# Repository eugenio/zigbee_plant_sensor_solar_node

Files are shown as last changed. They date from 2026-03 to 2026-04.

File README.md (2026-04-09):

# Zigbee Plant Sensor Solar Node

Solar-powered environmental monitoring node for outdoor plant care. Measures temperature, humidity, light, soil moisture, and battery state via Zigbee 802.15.4 — integrates with Home Assistant, Zigbee2MQTT, and ZHA.

## Motivation

Commercial plant sensors are either battery-hungry, lack solar charging, or miss key measurements. This node combines an MPPT solar charger with deep-sleep Zigbee to achieve indefinite outdoor operation while reporting six sensor channels.

## Hardware Overview

| Block | Component | Function |
| --- | --- | --- |
| MCU | ESP32-C6-MINI-1-N4 | Zigbee 802.15.4 / WiFi / BLE, 4MB flash |
| MPPT Charger | SPV1040T | Autonomous solar boost charger, 5W max  |
| LDO | HT7833 | 3.3V 500mA, 4uA quiescent |
| Battery Protection | XB3306D | Overcharge / overdischarge / overcurrent |
| Temp/Humidity | SHT40 | +/-0.2 degC, +/-1.8% RH (onboard) |
| Ambient Light | VEML7700 | 0.0036 - 120k lux |
| Fuel Gauge | MAX17048 | Li-Po SOC estimation, low-battery alert |
| External Temp | ADS1115 + NTC 10k  | 0.1 degC resolution, metal-tip probe |
| Expansion | 2x Qwiic I2C | Soil moisture, EC sensor |

**Board**: 60 x 48 mm, 4-layer, 1.6mm FR4

## Quick Start

```bash
# 1. Install atopile
pip install atopile

# 2. Clone and build
git clone <repo-url> && cd zigbee_plant_sensor_solar_node
ato build

# 3. Open PCB in KiCad
kicad layouts/default/default.kicad_pcb
```

## Project Structure

```text
.
├── main.ato                    # Top-level schematic (App module)
├── micromppt.ato               # MPPT solar charger (SPV1040T)
├── ldo.ato                     # 3.3V LDO (HT7833)
├── loadswitch.ato              # P-FET high-side load switch (SI2301CDS)
├── ntc_adc.ato                 # External NTC thermistor (ADS1115)
├── xiao_esp32c6.ato            # ESP32-C6 MCU driver
├── ato.yaml                    # Atopile project config + dependencies
├── pixi.toml                   # Pixi environment config
├── parts/                      # Component packages (32 parts, 4 files each)
│   ├── Texas_Instruments_ADS1115IRUGR/   # .ato + .kicad_mod + .kicad_sym + .step
│   ├── STMicroelectronics_SPV1040T/
│   ├── Espressif_Systems_ESP32_C6_MINI_1_N4/
│   └── ...                     # Resistors, caps, connectors, ICs
├── layouts/default/            # KiCad PCB layout (60x48mm, 4-layer)
│   ├── default.kicad_pcb
│   ├── default.kicad_sch
│   └── default.kicad_pro
├── docs/
│   ├── pcb_placement_strategy.md
│   ├── power_budget.md
│   ├── uml/architecture.puml  # System block diagram
│   └── adr/ADR-001-external-ntc-thermistor.md
└── scripts/
    └── place_components.py     # Automated PCB placement

176 tracked files. Atopile dependencies (sensirion-sht40, vishay-veml7700,
maxim-max17048, sparkfun-qwiic) are gitignored and reinstalled by `ato build`.
```

## Power Budget

| Mode | Current | Duration | Notes |
| --- | --- | --- | --- |
| Deep Sleep | ~82 uA | 99% of time | Fuel gauge + LDO quiescent |
| Active (sense + TX)| ~120 mA | ~500 ms | Zigbee transmit burst |
| Solar input | 200-400 mA | Daylight hours | 5V / 1W panel via MPPT |

See [docs/power_budget.md](docs/power_budget.md) for detailed analysis.

## Architecture

See [docs/uml/architecture.puml](docs/uml/architecture.puml) for the system block diagram.

## License

MIT

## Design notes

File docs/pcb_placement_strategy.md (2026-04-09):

# PCB Placement Strategy — Zigbee Plant Sensor Solar Node

## Board Parameters
- **PCB file**: `layouts/default/default.kicad_pcb`
- **Current size**: 245.5 x 137.5 mm (oversized — target ~60x48mm per enclosure)
- **Layers**: 4 (2-signal + 2-ground/power recommended)
- **Footprints**: 60 total, 235 pads, 0 tracks (unrouted)
- **Stack**: 1.6mm FR4

## Functional Blocks (placement groups)

### Block A — Solar MPPT Charger (SPV1040T)
**Components**: SPV1040T IC, L1 (XAL6060 inductor), Cin (10µF), Cout1 (4.7µF), Cout2 (10µF), R1/R2 (voltage divider 1%), R3, Rf1, Rf2, Rs (10mΩ sense), Cinsns, Coutsns, Cf, SRV05-4 (ESD), D_rpv (reverse polarity Schottky)
**Connectors**: J_solar (JST PH 2-pin), J_battery (JST PH 2-pin)
**Placement rules**:
- Keep inductor L1 within 3mm of SPV1040T LX pin
- Cin close to VIN, Cout1/Cout2 close to VOUT
- Rs (current sense) between IC VOUT and battery output — short, wide traces
- Voltage divider R1/R2 near VCTRL pin — keep traces short (high impedance)
- Solar connector at board edge
- Battery connector at board edge (same side or adjacent)
- Group entire MPPT section in one corner

### Block B — Battery Protection (XB3306D)
**Components**: XB3306D IC, C_bpc (100nF), R_bpc (100Ω)
**Placement**: Adjacent to battery connector, between MPPT output and battery JST

### Block C — LDO Power (HT7833)
**Components**: HT7833 IC, c_in (1µF), c_out (1µF), c_bulk (100µF 0805)
**Placement rules**:
- Between battery rail (Block A output) and 3.3V rail (Block D input)
- c_bulk (100µF) as close to VOUT as possible — critical for TX transient
- c_in close to VIN pin
- Keep short, wide power traces from battery to LDO to MCU

### Block D — ESP32-C6 MCU
**Components**: ESP32-C6-MINI-1-N4 module, c_dec_1 (10µF), c_dec_2 (100nF), r_en (10k), c_en (1µF), r_boot (10k), btn_boot, btn_reset, USB-C connector, r_cc1/r_cc2 (5.1k), USB ESD (SRV05-4)
**Placement rules**:
- **CRITICAL: Antenna keepout** — 3.5mm clearance from module edge (antenna end) on ALL copper layers. No traces, pours, or vias in this zone.
- Antenna must point toward board edge or overhang — never toward ground plane
- Place module so antenna faces AWAY from MPPT switching noise
- Decoupling caps c_dec_1 and c_dec_2 within 2mm of P3V3 pin
- USB-C connector at board edge, close to IO12/IO13 pads
- Boot/reset buttons accessible from board edge
- Keep I2C lines (IO6/IO7) routed toward sensor area

### Block E — Sensors (on switched power rail)
**Components**: SHT40 (DFN-4), VEML7700 (LED-SMD-4P), decoupling caps (2x 100nF)
**Placement rules**:
- SHT40: Away from heat sources (LDO, MPPT, MCU). Ideally near board edge with thermal isolation slot
- VEML7700: Near board edge with unobstructed view (light sensor — no tall components nearby)
- Both on same I2C bus — minimize trace length to MCU IO6/IO7

### Block F — Fuel Gauge (always on, main 3.3V)
**Components**: MAX17048 (TDFN-8), bypass_cap (1µF), battery_cap (1µF), q_pulldown (10k), alert_pullup (10k)
**Placement**: Near battery connection (senses CELL voltage) and close to MCU (I2C + ALERT to GPIO2)

### Block G — Qwiic Connectors
**Components**: 2x BM04B-SRSS-TB (4-pin SMD)
**Placement**: Board edge, accessible for cable connection. Same side preferred.

### Block H — Load Switches (2x SI2301CDS P-FET)
**Components per switch**: SI2301CDS (SOT-23), r_gate_pu (100k), r_gate (10k)
- **MPPT gate**: Between battery rail and MPPT power input. Near Block A.
- **Sensor gate**: Between 3.3V rail and sensor power rail. Near Block E.

### Block I — I2C Pull-ups
**Components**: r_sda_pu (2.2k), r_scl_pu (2.2k)
**Placement**: Central location near MCU, on the I2C bus trunk before it fans out to sensors/Qwiic

### Block J — External NTC Thermistor (ADS1115)
**Components**: ADS1115IRUGR (X2QFN-10), R_ref (10k 0.1% 0402), C_dec (100nF 0402), CN_ntc (JST PH 2-pin)
**Placement rules**:
- ADS1115 near fuel gauge (Block F) — both on I2C bus, both always-on
- R_ref within 3mm of ADS1115 AIN0 pin (short high-impedance trace)
- C_dec within 2mm of ADS1115 VDD pin
- CN_ntc at board edge — NTC probe cable exits enclosure, only metal tip protrudes
- Keep analog input traces away from MPPT switching noise and I2C clock lines
- Guard AIN0 trace with GND on adjacent layers

### Block K — Mounting Holes
**Components**: 4x MountingHole_3.2_M3
**Placement**: 4 corners of the board, inset ~3mm from edges

## Recommended Floor Plan (60x48mm target)

```
┌─────────────────────────────────────────────────────────┐
│ [MH]                                             [MH]  │
│                                                         │
│  ┌─────────┐  ┌──────────┐  ┌───────────────────────┐  │
│  │ MPPT    │  │ LDO      │  │ ESP32-C6-MINI-1       │  │
│  │ Block A │  │ Block C  │  │ Block D               │  │
│  │         │  │ +100µF   │  │                       │  │
│  │ L1  IC  │  │          │  │         ┌─────────┐   │  │
│  │         │  │          │  │         │ ANTENNA │   │  │
│  └─────────┘  └──────────┘  │         │ KEEPOUT │   │  │
│  [J_solar]                   │         └─────────┘   │  │
│  [J_batt] [BPC]             └───────────────────────┘  │
│                                                         │
│  ┌───────┐ ┌───────┐  [I2C PU]  ┌────┐ ┌────┐         │
│  │SHT40  │ │VEML   │            │Qwc1│ │Qwc2│  [USB-C]│
│  │Block E│ │7700   │  [Fuel     └────┘ └────┘         │
│  └───────┘ └───────┘   Gauge]    Block G               │
│  [CN_ntc]   [ADS1115]  Block F                         │
│              Block J                                    │
│ [MH]                                             [MH]  │
└─────────────────────────────────────────────────────────┘

Power flow: Solar → MPPT → Battery → LDO → 3.3V → MCU/Sensors
Signal flow: Sensors → I2C bus → MCU → Zigbee antenna (RF out)
```

## Placement Priority Order

1. **ESP32-C6 module** — largest component, antenna determines board edge orientation
2. **MPPT IC + inductor** — high-current switching, needs tight layout
3. **LDO + bulk cap** — power path between MPPT and MCU
4. **Connectors** (solar, battery, USB-C, Qwiic) — board edges
5. **Sensors** (SHT40, VEML7700) — thermal/optical considerations
6. **Fuel gauge** (MAX17048) — near battery + MCU
7. **Load switches** — in power path, near their respective blocks
8. **NTC ADC** (ADS1115) — near fuel gauge, NTC connector at board edge
9. **Passives** — close to their parent ICs
10. **Mounting holes** — 4 corners

## Critical Layout Rules

1. **Antenna keepout**: 3.5mm clearance, no copper on any layer
2. **MPPT switching loop**: Minimize area of L1→LX→VOUT→Cout→GND loop
3. **Current sense**: Rs (10mΩ) Kelvin connection — separate sense and power traces
4. **Ground plane**: Continuous on layer 2, split only if necessary between analog/digital
5. **Thermal relief**: SHT40 needs thermal isolation from hot components
6. **High-impedance traces**: R1/R2 voltage divider, MPPT sense lines — guard with ground
7. **Power traces**: Battery and 3.3V rails minimum 0.5mm width, 1mm preferred
8. **NTC analog trace**: AIN0 from R_ref/NTC junction to ADS1115 — short, guarded with GND, away from MPPT/I2C clock

## GPIO Quick Reference

| GPIO | Function | Direction | Connected To |
|---|---|---|---|
| IO0  | MPPT gate | Output (active low) | SI2301CDS gate → MPPT power |
| IO1  | Sensor gate | Output (active low) | SI2301CDS gate → sensor rail |
| IO2  | Battery alert | Input (active low) | MAX17048 nALRT |
| IO6  | I2C SDA | Bidirectional | All sensors + Qwiic |
| IO7  | I2C SCL | Output | All sensors + Qwiic |
| IO9  | Boot select | Input (pulled high) | Boot button to GND |
| IO12 | USB D- | Bidirectional | USB-C connector |
| IO13 | USB D+ | Bidirectional | USB-C connector |
| IO16 | UART TX | Output | Debug header (optional) |
| IO17 | UART RX | Input | Debug header (optional) |

## How to Execute

After restarting Claude Code (to load the kicad-pcb MCP server):

```
Use the pcb-placement-specialist agent to place components according to
this strategy document. The KiCad MCP tools are configured as "kicad-pcb"
and expose: list_pcb_footprints, get_pcb_statistics, setup_pcb_layout,
analyze_pcb_nets, run_drc, export_gerber.

PCB file: layouts/default/default.kicad_pcb
Strategy: docs/pcb_placement_strategy.md
```

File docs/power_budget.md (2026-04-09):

# Power Budget — Zigbee Plant Sensor Solar Node

## Component Power Consumption

| Component | Function | V_supply | Active Current | Sleep Current |
|---|---|---|---|---|
| ESP32-C6-MINI-1-N4 | MCU + Zigbee | 3.3V | 120 mA (TX @ 0 dBm), 73 mA (RX), 19 mA (CPU only) | 7 uA (deep sleep) |
| SHT40 | Temp/Humidity | 1.08-3.6V | 150 uA | 0.08 uA |
| VEML7700 | Light Sensor | 2.5-3.6V | 45 uA | 0.5 uA |
| MAX17048 | Fuel Gauge | 2.5-4.5V | 23 uA | 4 uA |
| SPV1040T | MPPT Charger | 0.3-5.5V | N/A | 60 uA (quiescent) |
| HT7833 | 3.3V LDO | 3.6-8V in | pass-through | 7 uA |
| XB3306D | Battery Protection | 2.5-6.0V | pass-through | 3 uA |

## Operating Parameters

- Readings every 5 minutes (288/day)
- Active duration per reading: ~500 ms (200 ms sensor read + 300 ms Zigbee TX/ACK)
- Battery: 3.7V nominal LiPo

## Active Current Budget (per 500 ms reading)

| Phase | Duration | ESP32-C6 | Sensors | Other | Subtotal |
|---|---|---|---|---|---|
| Sensor read (CPU, no RF) | 200 ms | 19 mA | ~0.2 mA | ~0.03 mA | ~19.2 mA |
| Zigbee TX + RX ACK | 300 ms | 120 mA | — | ~0.03 mA | ~120 mA |
| **Weighted average** | **500 ms** | | | | **~80 mA** |

With 1.2x safety margin: **~96 mA average per active period**

## Sleep Current Budget

| Component | Current |
|---|---|
| ESP32-C6 (deep sleep) | 7.0 uA |
| SHT40 (idle) | 0.08 uA |
| VEML7700 (shutdown) | 0.5 uA |
| MAX17048 (hibernate) | 4.0 uA |
| SPV1040T (quiescent) | 60.0 uA |
| HT7833 (quiescent) | 7.0 uA |
| XB3306D (standby) | 3.0 uA |
| **Total** | **81.6 uA** |

Note: SPV1040T dominates sleep budget at 73% of total.

## Daily Energy Budget

### At 3.3V rail

| Mode | Current | Time/day | Energy |
|---|---|---|---|
| Active | 96 mA | 144 s (0.04 h) | 3.84 mAh / 12.67 mWh |
| Sleep | 81.6 uA | 23.96 h | 1.96 mAh / 6.45 mWh |
| **Subtotal** | | | **5.80 mAh / 19.12 mWh** |

### At battery level

- HT7833 LDO efficiency: Vout/Vin = 3.3V/3.7V = 89.2%
- SPV1040T quiescent (direct from battery): 60 uA x 24h x 3.7V = 5.33 mWh/day
- XB3306D (direct from battery): 3 uA x 24h x 3.7V = 0.27 mWh/day

| Item | Energy/day |
|---|---|
| 3.3V rail (through LDO) | 21.43 mWh |
| SPV1040T quiescent | 5.33 mWh |
| XB3306D standby | 0.27 mWh |
| **Total from battery** | **~27 mWh/day** |

**With safety margin: ~30 mWh/day**

## Battery Autonomy (no solar)

| Battery | Capacity | Realistic Days (x0.7 derating) |
|---|---|---|
| 500 mAh | 1.85 Wh | ~43 days |
| 1000 mAh | 3.7 Wh | ~86 days |
| 2000 mAh | 7.4 Wh | ~173 days |

## Solar Panel Sizing

Efficiency chain:
- SPV1040 charger: ~90%
- Battery charge/discharge: ~90%
- Panel derating (angle, clouds, aging): ~70%
- **Combined: 56.7%**

Required solar input: 30 mWh / 0.567 = **52.9 mWh/day**

| Panel | Rated Power | Peak Sun Hours Needed |
|---|---|---|
| 0.5W (60x60mm) | 500 mW | 6.3 min |
| 1W (110x70mm) | 1000 mW | 3.2 min |
| 2W (110x136mm) | 2000 mW | 1.6 min |

## Selected Configuration

- **Solar panel**: ~2W, **4-cell** (Vmpp ~2.0-2.2V, Impp ~0.9-1.0A)
  - CRITICAL: SPV1040T is a boost-only converter (Vin < Vout required).
    A 5V panel (Voc ~6.5V) exceeds Vin_max=5.5V and prevents MPPT tracking.
    Must use a low-voltage panel where Vmpp < Vbat (4.2V).
  - Alternative: replace SPV1040T with buck-boost MPPT (e.g., SPV1050, CN3791)
    if a 5V+ panel is preferred.
- **Battery**: 1000 mAh LiPo (3.7V nominal)
- **Battery autonomy**: ~86 days without sun (with MPPT gate: ~120+ days)
- **Solar sufficiency**: needs <2 minutes of direct sun per day

## Design Improvements (rev 2)

- **R1/R2 tolerance**: Changed from 10% to 1% — prevents overcharge (4.53V risk)
- **LDO bulk cap**: Added 100µF output cap — absorbs 120mA Zigbee TX transient
- **I2C pull-ups**: Centralized single 2.2k pair — was 6x10k stacked (3.3k effective)
- **Solar reverse protection**: Added Schottky diode on Vpv input
- **USB ESD**: Added SRV05-4 TVS on USB D+/D-
- **MPPT power gate**: P-FET load switch (SI2301CDS) on GPIO0 — saves 60µA at night
- **Sensor power gate**: P-FET load switch on GPIO1 — cuts external sensor power during sleep
- **Battery UVLO**: MAX17048 ALERT wired to GPIO2 — wakes MCU for low-battery shutdown
- **RF keepout**: Documented 3.5mm antenna clearance zone requirement

## ESP32-C6 802.15.4 TX Power Levels

| TX Power | Current |
|---|---|
| +19 dBm | 305 mA |
| +12 dBm | 190 mA |
| 0 dBm | 120 mA |
| -16 dBm | 86 mA |

Default assumption: 0 dBm (good indoor/outdoor range, reasonable power).

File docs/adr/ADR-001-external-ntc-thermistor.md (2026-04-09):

# ADR-001: External NTC Thermistor with ADS1115 ADC

## Status

Accepted

## Context

The onboard SHT40 temperature sensor is mounted on the PCB inside a solar-exposed enclosure. During sunny conditions, the PCB heats up significantly (measured 15-20 degC above ambient), making the onboard reading unreliable for true ambient temperature. The node needs accurate outdoor temperature for plant care decisions.

Requirements:
- Range: -30 to +100 degC
- Resolution: 0.1 degC
- Only the metal sensing tip protrudes from the enclosure
- Short cable (10-30 cm)
- Low cost, simple integration

## Decision

Use an external 10k NTC thermistor probe with a dedicated ADS1115 16-bit delta-sigma ADC for readout. The NTC connects via a JST PH 2-pin connector. A precision 10k 0.1% reference resistor (YAGEO RT0402BRD0710KL, 25ppm/degC) forms a voltage divider read by the ADS1115.

The ADS1115 is on the always-on 3.3V rail (not the switched sensor rail) with I2C address 0x48.

Firmware will use Steinhart-Hart 3-point calibration to achieve +/-0.1 degC absolute accuracy from a standard +/-1% NTC probe.

## Consequences

### Positive
- True ambient temperature independent of enclosure heating
- 0.02 degC ADC resolution (16-bit) far exceeds the 0.1 degC target
- ADS1115 shares existing I2C bus — no additional GPIOs needed
- NTC probe is cheap (~1-3 EUR) and mechanically simple

### Negative
- Adds 4 components to BOM: ADS1115 (1.92 EUR), precision resistor, decoupling cap, JST connector
- Requires firmware Steinhart-Hart calibration per probe
- NTC nonlinearity requires lookup table or polynomial for accuracy across full range

### Neutral
- ADS1115 has 4 analog inputs — 3 are unused and available for future sensors
- I2C bus now has 5 devices (SHT40, VEML7700, MAX17048, ADS1115, + Qwiic) — well within bus capacity

## Alternatives Considered

| Alternative | Why Rejected |
|---|---|
| ESP32-C6 internal ADC (12-bit) | INL +/-5 LSB gives +/-0.6 degC — insufficient for 0.1 degC target |
| External digital probe (DS18B20, 1-Wire) | Requires additional GPIO + 1-Wire protocol; 0.5 degC accuracy without calibration |
| External SHT40 on cable (I2C) | I2C not reliable over cables >10cm without bus extender; address conflict with onboard SHT40 |
| Pt1000 RTD | More linear and accurate but requires excitation current source or Wheatstone bridge — more complex circuit for marginal benefit over calibrated NTC |

## References

- ADS1115 datasheet: Texas Instruments SBAS444
- NTC Steinhart-Hart calibration: Steinhart & Hart, 1968, "Calibration curves for thermistors"
- YAGEO RT0402BRD0710KL: 10k 0.1% thin film, 25ppm/degC

---
*ADRs are immutable once Accepted. To revise, create a new ADR with status "Supersedes ADR-001".*

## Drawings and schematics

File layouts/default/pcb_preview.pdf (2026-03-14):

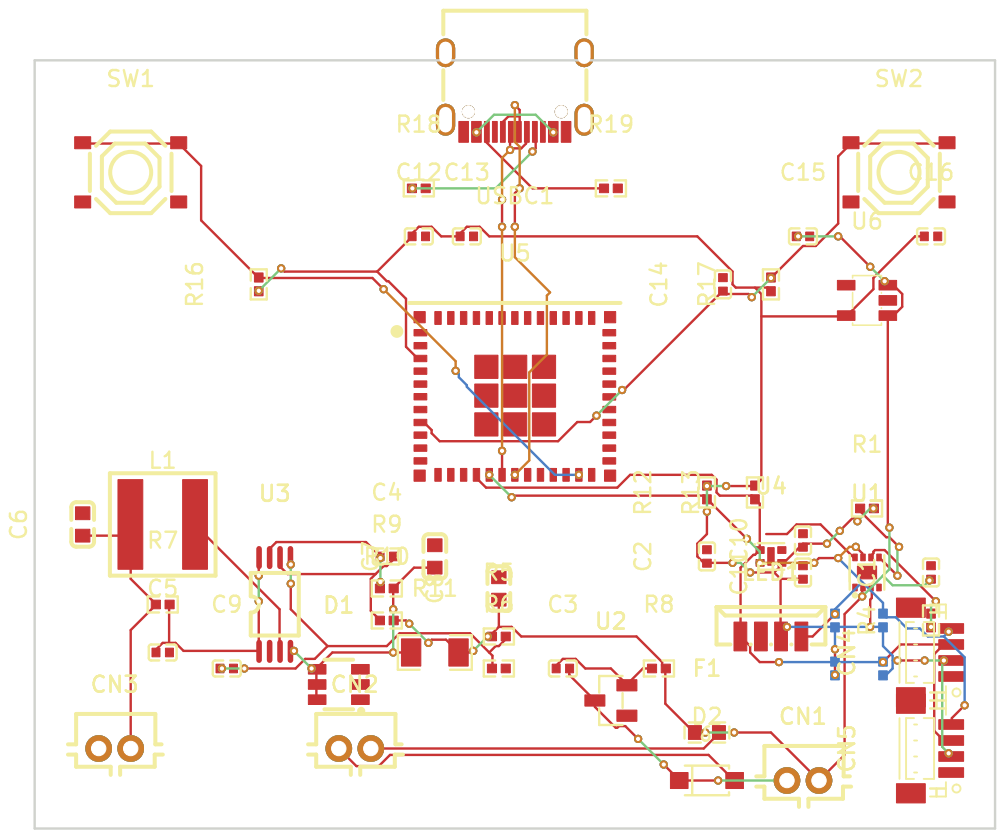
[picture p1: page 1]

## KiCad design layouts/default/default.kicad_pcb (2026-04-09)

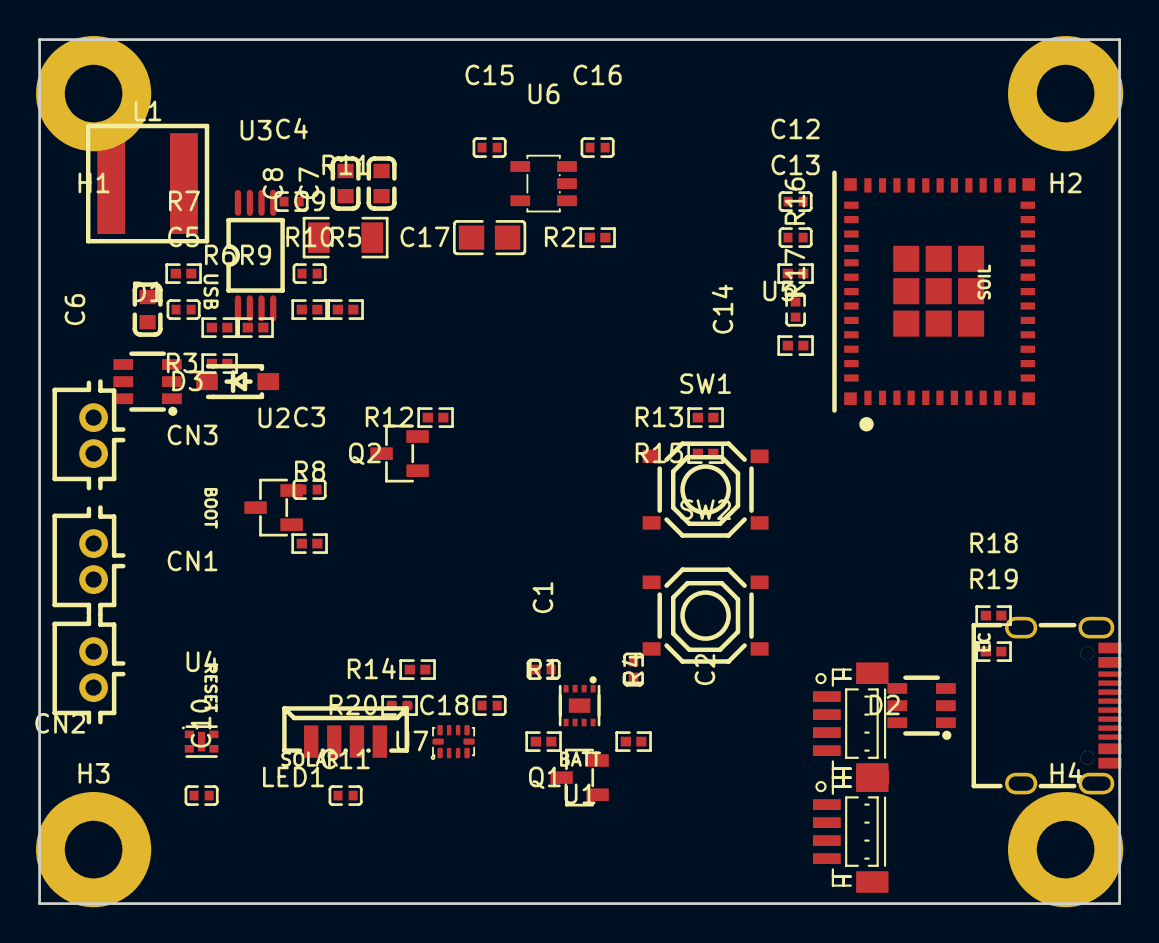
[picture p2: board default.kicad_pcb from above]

Board: 4 copper layers, 60.0 x 48.0 mm, 64 parts (0 on the bottom side), 28 nets, no tracks yet.

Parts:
C1, C2, C4, C14, C15, C16: 1µF ±10%; C0402
C3, C5, C10, C11, C13, C18: 100nF ±10%; C0402
C6, C8: 10µF ±10%; C0603
C7: 4.7µF ±10%; C0603
C9: 1nF ±10%; C0402
C12: 10µF ±20%; C0402
C17: 100µF ±20%; C0805
CN1, CN2, CN3: CONN-TH_B2B-PH-K-S
CN4, CN5: CONN-SMD_BM04B-SRSS-TB
D1, D2: SOT-23-6_L2.9-W1.6-P0.95-LS2.8-BR
D3: Vf {ℝ+}V; SOD-123_L2.7-W1.6-LS3.7-RD-1
H1, H2, H3, H4: MountingHole_3.2_M3
L1: L {ℝ+}H; IND-SMD_L6.6-W6.4
LED1: LED-SMD_4P-L6.8-W2.4_VEML7700-TR
Q1, Q2: SOT-23-3_L2.9-W1.3-P1.90-LS2.4-BR
R1, R4, R13, R15, R16, R17: 10kΩ ±1%; R0402
R2, R3: 2.2kΩ ±1%; R0402
R5: 1MΩ ±1%; R0402
R6: 422kΩ ±1%; R0402
R7, R9, R10: 1kΩ ±1%; R0402
R8: 100Ω ±1%; R0402
R11: 10mΩ ±1%; R1206
R12, R14: 100kΩ ±1%; R0402
R18, R19: 5.1kΩ ±1%; R0402
R20: R0402
SW1, SW2: SW-SMD_4P-L5.1-W5.1-P3.70-LS6.5-TL_H1.5
U1: TDFN-8_L2.0-W2.0-P0.50-BL-EP1.2
U2: SOT-23-3_L2.9-W1.3-P1.90-LS2.4-BR
U3: TSSOP-8_L4.4-W3.0-P0.65-LS6.4-BL
U4: DFN-4_L1.5-W1.5-P0.8-TL-EP
U5: WIFIM-SMD_61P-L16.6-W13.2-P0.80-ESP32-C6-MINI-1-N4
U6: SOT-23-5_L3.0-W1.7-P0.95-LS2.8-BR
U7: X2QFN-10_L2.0-W1.5-P0.50-BL
USBC1: USB-C_SMD-TYPE-C-31-M-12_1

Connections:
1: CN2.1, R20.2, U7.4
5: R1.1, U1.5, U5.5
17: D2.6, U5.17, USBC1.A7, USBC1.B7
18: D2.4, U5.18, USBC1.A6, USBC1.B6
A: R16.2, SW1.1, SW1.2, U5.23
A5: R18.1, USBC1.A5
B5: R19.1, USBC1.B5
C_bpc-power-hv: C3.1, R8.1, U2.2
Cf-power-hv: C4.1, R9.1, U3.7
Cf-power-lv: C4.2, R10.1, U3.6
Cinsns-power-hv: C5.1, R7.2, U3.1, U3.8
Cout1-power-hv: C7.1, D1.4, D1.5, D1.6, R9.2, R11.1, U3.4
Coutsns-power-hv: C9.1, R5.2, R6.1, U3.5
G: Q1.1, R12.2, R13.2
LX: L1.2, U3.3
QSTRT: R4.1, U1.6
SCL: CN4.4, CN5.4, LED1.1, R2.2, U1.7, U4.2, U5.16, U7.10
SDA: CN4.3, CN5.3, LED1.4, R3.2, U1.8, U4.1, U5.15, U7.9
Vbatr-lv: C3.2, CN1.2, U2.3
anode: CN3.1, D3.2
c_en-power-hv: C14.1, R17.2, SW2.1, SW2.2, U5.8
cathode: C6.1, D3.1, L1.1, R7.1
hv: C1.1, C2.1, C8.1, C10.1, C11.1, C12.1, C13.1, C15.1, C16.1, C17.1, C18.1, CN1.1, CN4.2, CN5.2, D2.5, LED1.2, Q1.2, Q2.2, Q2.3, R1.2, R2.1, R3.1, R5.1, R8.2, R10.2, R11.2, R12.1, R14.1, R16.1, R17.1, R20.1, U1.2, U1.3, U4.3, U5.3, U6.1, U6.3, U6.5, U7.8
line: R13.1, U5.12
lv: C1.2, C2.2, C5.2, C6.2, C7.2, C8.2, C9.2, C10.2, C11.2, C12.2, C13.2, C14.2, C15.2, C16.2, C17.2, C18.2, CN2.2, CN3.2, CN4.0, CN4.1, CN5.0, CN5.1, D1.1, D1.2, D1.3, D2.1, D2.2, D2.3, LED1.3, R4.2, R6.2, R18.2, R19.2, SW1.3, SW1.4, SW2.3, SW2.4, U1.1, U1.4, U1.9, U2.1, U3.2, U4.4, U4.5, U5.1, U5.2, U5.11, U5.14, U5.36, U5.37, U5.38, U5.39, U5.40, U5.41, U5.42, U5.43, U5.44, U5.45, U5.46, U5.47, U5.48, U5.49, U5.50, U5.51, U5.52, U5.53, U6.2, U7.1, U7.3, U7.5, U7.6, U7.7, USBC1.1, USBC1.2, USBC1.3, USBC1.4, USBC1.A1B12, USBC1.B1A12
power_usb-hv: USBC1.A4B9, USBC1.B4A9
sensor_gate-G: Q2.1, R14.2, R15.2
sensor_gate-enable-line: R15.1, U5.13

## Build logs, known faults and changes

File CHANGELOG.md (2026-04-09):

# Changelog

All notable changes to this project are documented here.
Format: [Keep a Changelog](https://keepachangelog.com/en/1.0.0/)

## [Unreleased]

### Added
- External NTC thermistor circuit: ADS1115 16-bit ADC + 10k 0.1% reference resistor + JST PH 2-pin probe connector for high-precision ambient temperature measurement (0.1 degC resolution, -30 to +100 degC)
- PCB component placement for 60x48mm 4-layer board following functional block strategy
- Automated placement script (`scripts/place_components.py`)
- PCB placement strategy document (`docs/pcb_placement_strategy.md`)
- P-FET high-side load switch module (`loadswitch.ato`) using SI2301CDS

### Changed
- ESP32-C6 module rotated 90 deg with antenna facing right board edge for optimal RF performance
- MPPT switching loop components placed within 3mm for minimal loop area

## [0.3.0] - 2026-03-14

### Added
- OpenSCAD parametric enclosure for 60x48mm PCB
- STEP exports for mechanical integration
- PCB preview renders
- Quilter autorouter candidate configurations

## [0.2.0] - 2026-03-01

### Added
- build123d enclosure design for 60x48mm PCB form factor

## [0.1.0] - 2026-02-25

### Added
- Complete schematic: ESP32-C6-MINI-1, SPV1040T MPPT charger, HT7833 LDO, SHT40, VEML7700, MAX17048 fuel gauge
- USB-C connector with ESD protection and CC resistors
- Boot and reset buttons
- Qwiic I2C expansion connectors (2x)
- Battery protection circuit (XB3306D)
- 4-layer PCB layout with initial routing
- KiCad project and schematic generation scripts

## [0.0.1] - 2026-02-24

### Added
- Initial project scaffold with atopile configuration

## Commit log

2026-02-25 Add solar-powered Zigbee plant sensor node design
    Single-PCB design with ESP32-C6-MINI-1-N4 (Zigbee/Thread),
    SPV1040T MPPT solar charger, HT7833 3.3V LDO, and I2C sensors
    (SHT40 temp/humidity, VEML7700 light, MAX17048 fuel gauge).
    Two Qwiic connectors for external soil moisture and EC probes.
    [C0402_L1.0-W0.5-H0.5.step, C0603_L1.6-W0.8-H0.8.step, CONN-SMD_4P-L6.0-W2.9-H4.3-P1.0.step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]
2026-02-25 Add USB-C connector, boot and reset buttons to ESP32-C6 driver
    Add programming interface: USB-C (TYPE-C-31-M-12) with CC pull-downs,
    boot button (GPIO9→GND) and reset button (EN→GND) using XKB tactile
    switches. Remove redundant USB ElectricLogic definitions.
    [R0402_L1.0-W0.5-H0.4.step, SW-SMD_4P-L5.1-W5.1-P3.70-LS6.5-TL_H1.5.STEP, USB-C_SMD-TYPE-C-31-M-12.step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]
2026-02-25 Route 4-layer PCB with corrected component placement
    Rewrote placement based on actual netlist assignments (atopile ref
    designators differ from schematic expectations). 60x48mm board with
    4-layer stackup, GND zones on In1.Cu/F.Cu/B.Cu. Autorouted with
    KiCadRoutingTools: 24/25 signal nets routed, 99/99 multipoint pads,
    81 vias. One minor SDA disconnection on U1.8 remains.
    [default.kicad_pcb]
2026-02-25 Add schematic generation, Quilter prep scripts, and updated PCB
    - Add generate_schematic.py to create KiCad 9 schematic from design
    - Add prepare_for_quilter.py to strip and prepare PCB for Quilter AI routing
    - Add generated schematic (default.kicad_sch)
    - Add quilter_upload/ directory with prepared KiCad project files
    - Update PCB layout with KiCad 9 formatting changes
    [default.kicad_pcb, default.kicad_sch]
2026-03-01 Add build123d enclosure for 60x48mm PCB
    Base: rounded box shell with M3 standoffs, heat-set insert holes from
    bottom, antenna thin-wall zone (Y- wall), battery retainer walls, and
    M5 cable gland hole (Y+ wall, X- side) for solar panel cable.
    Lid: flat plate with inner plug walls, countersunk M3 screw holes.
    Removed from original OpenSCAD design: USB-C cutout, button holes,
    Qwiic slots, PG7 cable gland array, light sensor window, hinge bosses.
    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
    [enclosure_base.step, enclosure_base.stl, enclosure_lid.step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]
2026-03-14 Add OpenSCAD enclosure, STEP exports, PCB previews, and Quilter candidates
    - Add OpenSCAD parametric enclosure (enclosure.scad) with full assembly exports
    - Add STEP export pipeline (export_all.py) with assembly components
    - Add STL/STEP files for base, lid, ball/nut/socket hardware
    - Add 3MF print files for hardware parts
    - Add PCB preview PDF/SVG for default layout
    - Add Quilter 4-layer and 6-layer PCB candidates
    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
    [Ball-18mm.3mf, Ball-18mm.stl, Nut-18mm.3mf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]
2026-04-09 feat: add external NTC thermistor (ADS1115) and place all components on 60x48mm board
    Add high-precision external NTC temperature measurement circuit using
    ADS1115 16-bit ADC (I2C addr 0x48) with 10k 0.1% reference resistor
    and JST PH 2-pin probe connector. This addresses solar heating bias
    on the onboard SHT40 sensor — the metal-tip NTC probe protrudes from
    the enclosure for true ambient temperature (0.1°C resolution).
    Also place all 64 components on the 60x48mm 4-layer PCB following the
    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
    [ADS1115IRUGR.step, C0402_L1.0-W0.5-H0.5.step, C0603_L1.6-W0.8-H0.8.step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]
2026-04-09 docs: add README, CHANGELOG, architecture diagram, and ADR-001
    - README: hardware overview table, quick start, project structure,
    power budget summary
    - CHANGELOG: version history from git log (Keep a Changelog format)
    - docs/uml/architecture.puml: system block diagram with power flow,
    I2C bus, GPIO control, and sensor topology
    - docs/adr/ADR-001: rationale for external NTC + ADS1115 over
    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
2026-04-09 chore: update .gitignore, add pixi config and remaining datasheets
    - .gitignore: add rules for simulation outputs, mempalace artefacts,
    KiCad lock files, and pre-route backups
    - pixi.toml/pixi.lock: project environment configuration
    - Add missing datasheets for ESP32-C6, USB-C, and button parts
2026-04-09 chore: remove obsolete quilter configs, STEP exports, and one-shot scripts
    Drop 43 files that are no longer needed:
    - quilter_upload/, quilter_4layer/, quilter_6layer/: old autorouter attempts
    - enclosure/export_step/: regenerable STEP exports
    - setup_board.py, prepare_for_quilter.py, generate_schematic.py: one-shot scripts
    - .github/: unused CI config
    [asm_ball_1.step, asm_ball_2.step, asm_base.step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]
2026-04-09 chore: remove vendored atopile deps, enclosure, and datasheets (326 -> 176 files)
    Atopile registry dependencies (sensirion-sht40, vishay-veml7700,
    maxim-max17048, sparkfun-qwiic) are reinstalled automatically by
    `ato build` — no need to track them in git.
    Also removed:
    - enclosure/ OpenSCAD and STEP files (regenerable)
    - PDF datasheets in parts/ (downloadable from LCSC)
    All gitignored to prevent re-accumulation. Build verified: passes.
    [Ball-18mm.stl, C0402_L1.0-W0.5-H0.5.step, CONN-SMD_4P-L6.0-W2.9-H4.3-P1.0.step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]
2026-04-09 chore: remove STEP 3D models, KiCad symbols, and 3mf meshes (176 -> 99 files)
    Binary STEP models (56MB), .kicad_sym symbol files, and .3mf meshes
    are all regenerable via `mcp__jlc__library_install` or JLC MCP tools.
    Only .ato definitions and .kicad_mod footprints remain in parts/.
    Build verified: ato build passes.
    [ADS1115IRUGR.step, Ball-18mm.3mf, C0402_L1.0-W0.5-H0.5.step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]
